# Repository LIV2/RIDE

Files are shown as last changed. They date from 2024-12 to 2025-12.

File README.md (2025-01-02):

# 🏍 RIDE - A500+ Fast Ram + IDE
## IDE + 11.37 Megabyte Fast RAM for the A500/A1000/A2000/CDTV
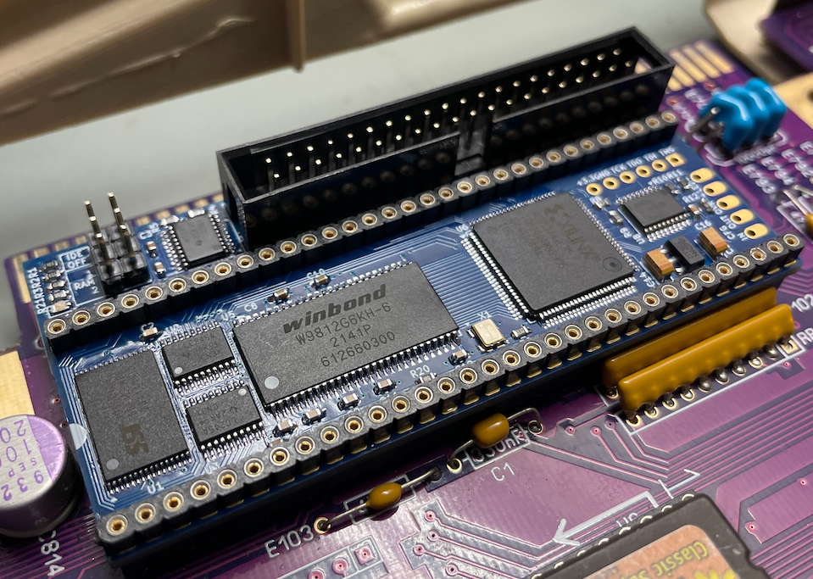
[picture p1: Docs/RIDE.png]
PCB


## Features
- 11.37MB Fast RAM - 1.5MB $C0/Ranger + 8MB Fast + 1.87 Bonus ($A00000)
- Autoboot IDE, Kick 1.3 compatible Open Source driver [lide.device](https://github.com/LIV2/lide.device)
- [Supports up to 2TB drives](https://github.com/LIV2/lide.device/#large-drive-4gb-support)
- Supports ATAPI Devices (CD/DVD-ROM, Zip disk etc - no IDEFix needed)
- Boot from ZIP/LS-120 etc
- [Boot from CD-ROM*](https://github.com/LIV2/lide.device/#boot-from-cdrom)
- SCSI Direct, NSD, TD64 support

## Table of contents
1. [Compatibility](#compatibility)
2. [Jumper settings](#jumper-settings)
3. [Connections](#connections)
4. [Enabling A0 Bonus RAM](#enabling-a0-bonus-ram)
5. [Programming](#programming)
6. [Ordering PCBs](#ordering-pcbs)
    * [PCB Order details](#pcb-order-details)
    * [PCB Assembly](#pcb-assembly)
    * [Bill of Materials](#bill-of-materials)
7. [License](#license)

## Compatibility

Compatible with Kickstart 1.3 and up.

## Jumper settings

**IDE Off**: Close to disable IDE  
**RAM1/RAM2**: Autoconfig RAM configuration
|RAM1|RAM2|Size|
|-|-|----|
|Open|Open|**8 MB**|
|Closed|Open|**4 MB**|
|Open|Closed|**2 MB**|
|Closed|Closed|**Disable**|

## Connections
* **LED**: Activity LED  
* **OVR**: **(Optional)** if connected this will enable the Ranger ($C00000) and Bonus ($A00000) RAM regions.  
Connect OVR to Gary pin 29 or pin 17 of the side expansion port  
* **CFGIN/OUT**: These pins allow this device to co-exist with other Autoconfig devices.
If there are no other Autoconfig devices in your system you can just leave these unconnected.  
If there *are* other Autoconfig devices you will want to use one of these to add the device to the chain.<br /><br />
In the Amiga 2000 you can connect CFGIN to U606 Pin 8 which will add the device to the end of the chain but **NOTE: This takes up the config signal for the leftmost slot (CN601) so do NOT install a Zorro card there**

## Enabling A0 Bonus RAM
The A0 Bonus RAM is not automatically picked up by kickstart and needs to be added using one of the included utilities.  
Note that the `addmem` command from Aminet will **NOT** work - the memory is not enabled until a specific RIDE register is set to enable it

To add the A0 Bonus RAM to the system you will need to use the `addram` command included in the RIDE-Software adf/lha found under [Releases](https://github.com/LIV2/RIDE/releases/latest).

Alternatively you can add the `bootrom` module to a custom kickstart so that this is done automatically at every boot.

## Programming

Program the CPLD using the relevant .jed file below (Right-click, Save as)
|Model|File|
|-----|----|
|A500(+)<br />A1000<br />A2000|[RIDE.jed](https://github.com/LIV2/RIDE/raw/master/Binary/RIDE.jed)|
|CDTV|[RIDE-CDTV.jed](https://github.com/LIV2/RIDE/raw/master/Binary/RIDE-CDTV.jed)|

You can find instructions on how to do that [here](https://linuxjedi.co.uk/2020/12/01/programming-xilinx-jtag-from-a-raspberry-pi/)

The IDE ROM can be programmed by booting from the latest lide-update.adf [here](https://github.com/LIV2/LIDE.device/releases/latest).

## Ordering PCBs

Download the latest Gerbers.zip from the latest release listed on the right-hand side of this page.

Also included in the release are the placement and bom files needed for JLCPCB's assembly service

### PCB Order details
This PCB has been designed to JLCPCB's 4-layer capabilities so I recommend ordering from them

* Layers: 4
* Surface finish: ENIG
* Remove Order Number: Yes

### PCB Assembly
The release files include the relevant BOM and CPL files for JLCPCB's Assembly service  
You can use the following options:  
* PCBA Type: Economic
* Assembly side: Top side
* Confirm Parts Placement: Yes (I recommend checking that all ICs have pin 1 in the correct location etc)

### Bill of materials
**Note**:
* The BOM lists a Mill-Max part for the pin sockets, however you can substitute these for some 9.7mm pin sockets like [these](https://www.aliexpress.com/item/33019740866.html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)  
* The 39SF010 flash can be substituted with 39SF020 or 39SF040 in TSOP-32

[BOM](https://html-preview.github.io/?url=https://github.com/LIV2/RIDE/blob/master/Docs/RIDE_bom.html)  
[HTML Interactive BOM](https://html-preview.github.io/?url=https://github.com/LIV2/RIDE/blob/master/Docs/RIDE-ibom.html)

## Acknowledgements
Thanks to [SukkoPera](https://github.com/SukkoPera) for supporting my early IDE prototype.

## License


This project is licensed under the GPL-2.0 only license

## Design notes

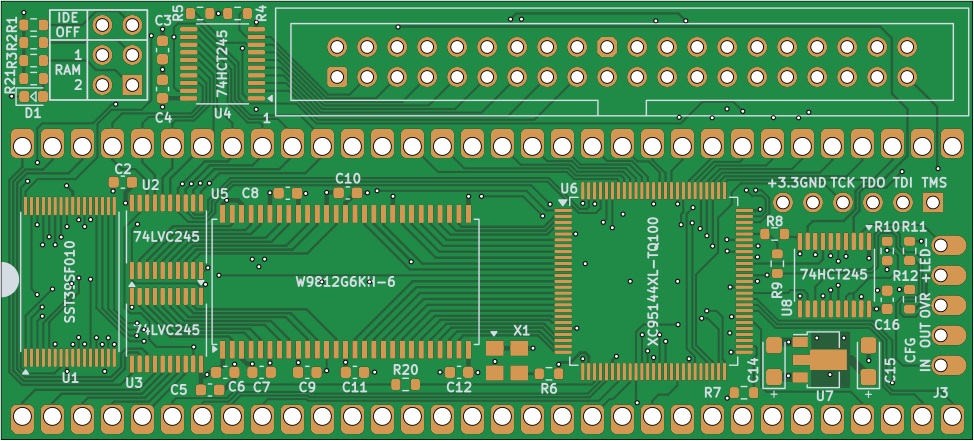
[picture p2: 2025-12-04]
Docs/PCB.png

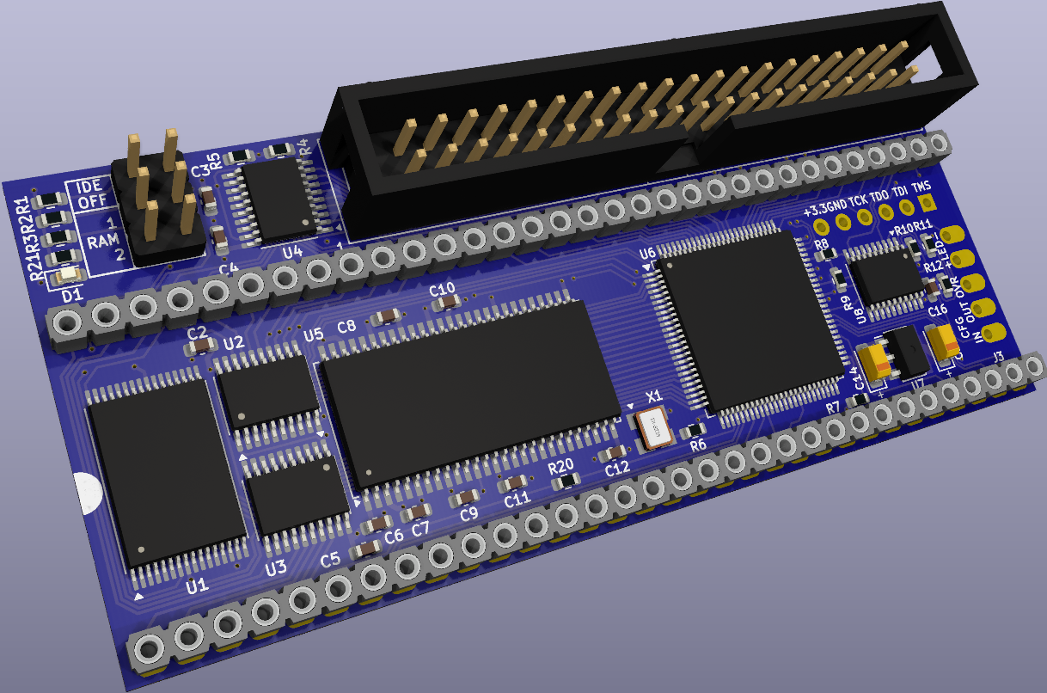
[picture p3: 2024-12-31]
Docs/PCB3D.png

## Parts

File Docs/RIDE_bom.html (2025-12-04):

 | RIDE Bill of materials
Qty | Comment | Designator | Footprint | Mouser Part | Digikey Part | LCSC Part
1 | AMIGA | AMIGA1 | DIP-64_W22.86mm | 575-643166 (https://www.mouser.com/ProductDetail/575-643166) | ED5764-64-ND (https://www.digikey.com/products/en?keywords=ED5764-64-ND) | (https://www.lcsc.com/product-detail/.html)
21 | 0.1u | C1,C2,C3,C4,C5,C6,C7,C8,C9,C10,C11,C12,C13,C16,C17,C18,C19,C20,C22,C23,C24 | C_0603_1608Metric | 80-C603C104K5RAC3121 (https://www.mouser.com/ProductDetail/80-C603C104K5RAC3121) | 399-C0603C104K5RAC3121CT-ND (https://www.digikey.com/products/en?keywords=399-C0603C104K5RAC3121CT-ND) | C14663 (https://www.lcsc.com/product-detail/C14663.html)
2 | 10u | C14,C15 | CP_EIA-3216-18_Kemet-A | 80-T491A106M020 (https://www.mouser.com/ProductDetail/80-T491A106M020) | 399-5152-1-ND (https://www.digikey.com/products/en?keywords=399-5152-1-ND) | C117023 (https://www.lcsc.com/product-detail/C117023.html)
2 | 10u | C21,C25 | C_0805_2012Metric_Pad1.18x1.45mm_HandSolder | 187-CL21A106KQFNNWE (https://www.mouser.com/ProductDetail/187-CL21A106KQFNNWE) | 1276-CL21A106KQFNNWECT-ND (https://www.digikey.com/products/en?keywords=1276-CL21A106KQFNNWECT-ND) | C15850 (https://www.lcsc.com/product-detail/C15850.html)
1 | 47uF | C26 | CP_EIA-3216-18_Kemet-A_Pad1.58x1.35mm_HandSolder | 80-T490A476M10ATE1K (https://www.mouser.com/ProductDetail/80-T490A476M10ATE1K) | 399-T490A476M010ATE1K0CT-ND (https://www.digikey.com/products/en?keywords=399-T490A476M010ATE1K0CT-ND) | C193224 (https://www.lcsc.com/product-detail/C193224.html)
1 | LED | D1 | LED_0603_1608Metric | 696-SML-LX0603GW (https://www.mouser.com/ProductDetail/696-SML-LX0603GW) | 67-1549-1-ND (https://www.digikey.com/products/en?keywords=67-1549-1-ND) | C136120 (https://www.lcsc.com/product-detail/C136120.html)
1 | Polyfuse 500mA Hold | F1 | Fuse_1206_3216Metric_Pad1.42x1.75mm_HandSolder | 576-1206L110-16WR (https://www.mouser.com/ProductDetail/576-1206L110-16WR) | 18-1206L110/16WRCT-ND (https://www.digikey.com/products/en?keywords=18-1206L110/16WRCT-ND) | C21714343 (https://www.lcsc.com/product-detail/C21714343.html)
1 | Conn_02x03_Odd_Even | J4 | PinHeader_2x03_P2.54mm_Vertical | 571-4-146262-1 (https://www.mouser.com/ProductDetail/571-4-146262-1) | 4-146262-1-ND (https://www.digikey.com/products/en?keywords=4-146262-1-ND) | C7501274 (https://www.lcsc.com/product-detail/C7501274.html)
1 | IDE | J1 | IDC-Header_2x20_P2.54mm_Vertical | 737-BHR-40-VUA (https://www.mouser.com/ProductDetail/737-BHR-40-VUA) | 2057-BHR-40-VUA-ND (https://www.digikey.com/products/en?keywords=2057-BHR-40-VUA-ND) | C9138 (https://www.lcsc.com/product-detail/C9138.html)
7 | 33 | R6,R7,R9,R13,R14,R18,R19 | R_0603_1608Metric | 279-CRG0603F33R (https://www.mouser.com/ProductDetail/279-CRG0603F33R) | 1712-CRG0603F33RCT-ND (https://www.digikey.com/products/en?keywords=1712-CRG0603F33RCT-ND) | C23140 (https://www.lcsc.com/product-detail/C23140.html)
3 | 150 | R12,R20,R21 | R_0603_1608Metric | 279-CRGP0603F150R (https://www.mouser.com/ProductDetail/279-CRGP0603F150R) | A130406CT-ND (https://www.digikey.com/products/en?keywords=A130406CT-ND) | C22808 (https://www.lcsc.com/product-detail/C22808.html)
11 | 10k | R1,R2,R3,R4,R5,R8,R10,R11,R15,R16,R17 | R_0603_1608Metric | 279-CRGH0603J10K (https://www.mouser.com/ProductDetail/279-CRGH0603J10K) | A126394CT-ND (https://www.digikey.com/products/en?keywords=A126394CT-ND) | C25804 (https://www.lcsc.com/product-detail/C25804.html)
3 | 74HCT245 | U4,U8,U9 | TSSOP-20_4.4x6.5mm_P0.65mm | 595-SN74HCT245PWR (https://www.mouser.com/ProductDetail/595-SN74HCT245PWR) | 296-8404-1-ND (https://www.digikey.com/products/en?keywords=296-8404-1-ND) | C6779 (https://www.lcsc.com/product-detail/C6779.html)
2 | 74LVC245 | U2,U3 | TSSOP-20_4.4x6.5mm_P0.65mm | 595-SN74LVC245APWR (https://www.mouser.com/ProductDetail/595-SN74LVC245APWR) | 296-1233-1-ND (https://www.digikey.com/products/en?keywords=296-1233-1-ND) | C7848 (https://www.lcsc.com/product-detail/C7848.html)
1 | AZ1117-3.3 | U7 | SOT-89-3 | 621-AZ1117CR-3.3TRG1 (https://www.mouser.com/ProductDetail/621-AZ1117CR-3.3TRG1) | AZ1117CR-3.3TRG1DICT-ND (https://www.digikey.com/products/en?keywords=AZ1117CR-3.3TRG1DICT-ND) | C460428 (https://www.lcsc.com/product-detail/C460428.html)
1 | SST39SF010 | U1 | TSOP-I-32_11.8x8mm_P0.5mm | (https://www.mouser.com/ProductDetail/) | 150-SST39SF010A-70-4C-TU-ND (https://www.digikey.com/products/en?keywords=150-SST39SF010A-70-4C-TU-ND) | (https://www.lcsc.com/product-detail/.html)
1 | W9812G6KH-6 | U5 | TSOP-II-54_22.2x10.16mm_P0.8mm | 454-W9812G6KH-6 (https://www.mouser.com/ProductDetail/454-W9812G6KH-6) | W9812G6KH-6-ND (https://www.digikey.com/products/en?keywords=W9812G6KH-6-ND) | C62379 (https://www.lcsc.com/product-detail/C62379.html)
1 | XC95144XL-TQ100 | U6 | TQFP-100_14x14mm_P0.5mm | 217-5144XL-10TQG100I (https://www.mouser.com/ProductDetail/217-5144XL-10TQG100I) | (https://www.digikey.com/products/en?keywords=) | C45126 (https://www.lcsc.com/product-detail/C45126.html)
1 | 50MHz | X1 | Oscillator_SMD_Abracon_ASE-4Pin_3.2x2.5mm | 520-ECS-2333-500-BNT (https://www.mouser.com/ProductDetail/520-ECS-2333-500-BNT) | XC1930CT-ND (https://www.digikey.com/products/en?keywords=XC1930CT-ND) | C5203552 (https://www.lcsc.com/product-detail/C5203552.html)
Color reference for columns:
KiCad Fields (default)
Generated Fields
User Fields
Empty Fields

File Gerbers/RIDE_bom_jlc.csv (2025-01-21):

Qty | Comment | Designator | Footprint | LCSC Part #
21 | 0.1u | C1,C2,C3,C4,C5,C6,C7,C8,C9,C10,C11,C12,C13,C16,C17,C18,C19,C20,C22,C23,C24 | C_0603_1608Metric | C14663
2 | 10u | C14,C15 | CP_EIA-3216-18_Kemet-A | C117023
2 | 10u | C21,C25 | C_0805_2012Metric_Pad1.18x1.45mm_HandSolder | C15850
1 | 47uF | C26 | CP_EIA-3216-18_Kemet-A_Pad1.58x1.35mm_HandSolder | C193224
1 | LED | D1 | LED_0603_1608Metric | C136120
1 | Polyfuse 500mA Hold | F1 | Fuse_1206_3216Metric_Pad1.42x1.75mm_HandSolder | C21714343
1 | Conn_02x03_Odd_Even | J4 | PinHeader_2x03_P2.54mm_Vertical | C7501274
1 | IDE | J1 | IDC-Header_2x20_P2.54mm_Vertical | C9138
7 | 33 | R6,R7,R9,R13,R14,R18,R19 | R_0603_1608Metric | C23140
3 | 150 | R12,R20,R21 | R_0603_1608Metric | C22808
11 | 10k | R1,R2,R3,R4,R5,R8,R10,R11,R15,R16,R17 | R_0603_1608Metric | C25804
3 | 74HCT245 | U4,U8,U9 | TSSOP-20_4.4x6.5mm_P0.65mm | C6779
2 | 74LVC245 | U2,U3 | TSSOP-20_4.4x6.5mm_P0.65mm | C7848
1 | AZ1117-3.3 | U7 | SOT-89-3 | C460428
1 | SST39SF010 | U1 | TSOP-I-32_11.8x8mm_P0.5mm
1 | W9812G6KH-6 | U5 | TSOP-II-54_22.2x10.16mm_P0.8mm | C62379
1 | XC95144XL-TQ100 | U6 | TQFP-100_14x14mm_P0.5mm | C45126
1 | 50MHz | X1 | Oscillator_SMD_Abracon_ASE-4Pin_3.2x2.5mm | C5203552

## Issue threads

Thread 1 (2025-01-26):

U1 SST39SF010 (and SST39SF020 and SST39SF040) is missing from JLCPCB

emanuelelaface, 2025-01-26:
Hi,

first of all thanks a lot for this great work. I'd love to build one of these memory expansions but I am not so good with tiny SMD to do by myself, so I am trying to order a pre-assembled version from JLCPCB but the U1 memory (the SST39SF010) is out of stock. Every variant like SST39SF020 or SST39SF040 is also not available in TSOP-32, so I wonder if you have a suggestion for a possible change that can work.
Thanks a lot!

LIV2, 2025-01-26:
Hi,

I haven't found any compatible parts that are still produced, and before I released this project the manufacturer discontinued the SST 39SF0x0 devices in TSOP packages

I don't think it's possible to order these parts through JLC parts any more but I do know that Digikey has some 39SF040s in stock for now: https://www.digikey.co.nz/short/n793qm5f

Other than that you would have to order some from eBay / Aliexpress I guess

emanuelelaface, 2025-01-26:
Thank you for your answer. The main problem for me is to solder the TSOP by myself, I will think what to do. Thanks a lot for your quick answer.

danko79, 2025-01-26:
Hi, due to the availability of the TSOP32 package, it is possible to revise the PCB in plcc32 format of the flash, i have same problem.

LIV2, 2025-01-29:
PLCC-32 is much larger, won't fit under the CPU and would need a larger PCB etc so I have no plans to revise it right now sorry.

Closed 2025-01-29.

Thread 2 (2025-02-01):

Anybody selling this?

mankeli, 2025-02-01:
Hi, I wonder if anyone is selling this already?

LIV2, 2025-02-03:
Hi @mankeli,

I'm not aware of anyone who is selling these currently but I'll ask around to see if anyone I know is planning to

LIV2, 2025-02-03:
The CPLD is still in stock at mouser for now:
https://www.mouser.com/ProductDetail/217-5144XL-10TQG100C
And also at LCSC / JLCPCB
https://www.lcsc.com/product-detail/Programmable-Logic-Device-CPLDs-FPGAs_AMD-XILINX-XC95144XL-10TQG100I_C1521163.html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

Digikey have a small amount of SST 39SF040 in stock which can be used for the flash
https://www.digikey.com/en/products/detail/microchip-technology/sst39sf040-70-4c-whe/2297836

Unfortunately there's no pin compatible alternatives for either, replacing the CPLD & Flash will require a lot of redesign work

LIV2, 2025-02-03:
It seems that Microchip have a new part for the flash but there's no stock in any distributors currently
https://www.digikey.co.nz/en/products/detail/microchip-technology/SST39SF010A-70-4C-TU/25903865

Closed 2025-08-10.

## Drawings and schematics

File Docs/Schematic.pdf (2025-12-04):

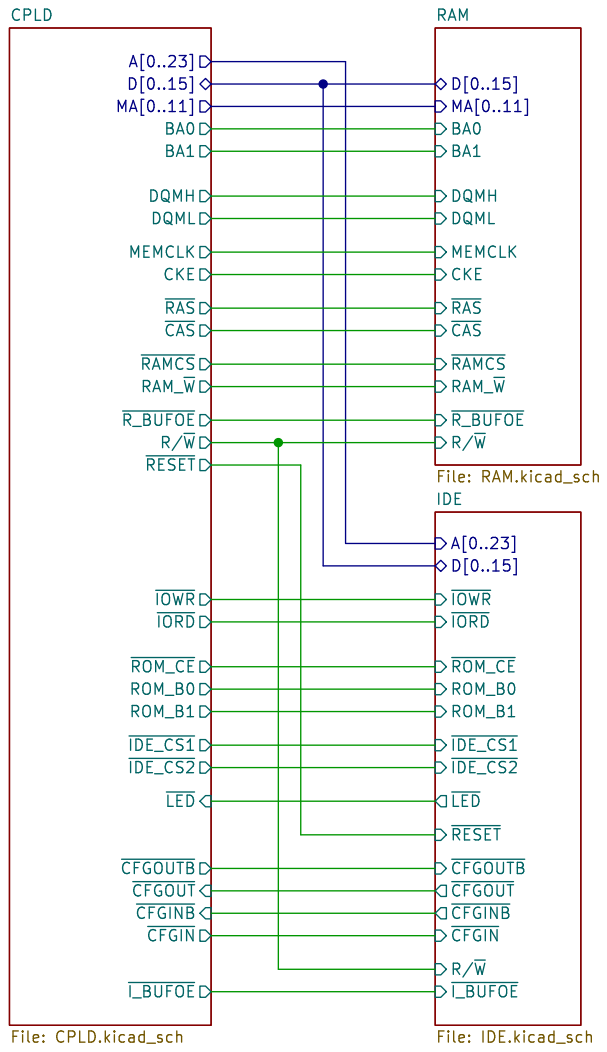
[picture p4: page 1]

Id: 1/4 Title: File: RIDE.kicad_sch Sheet: /

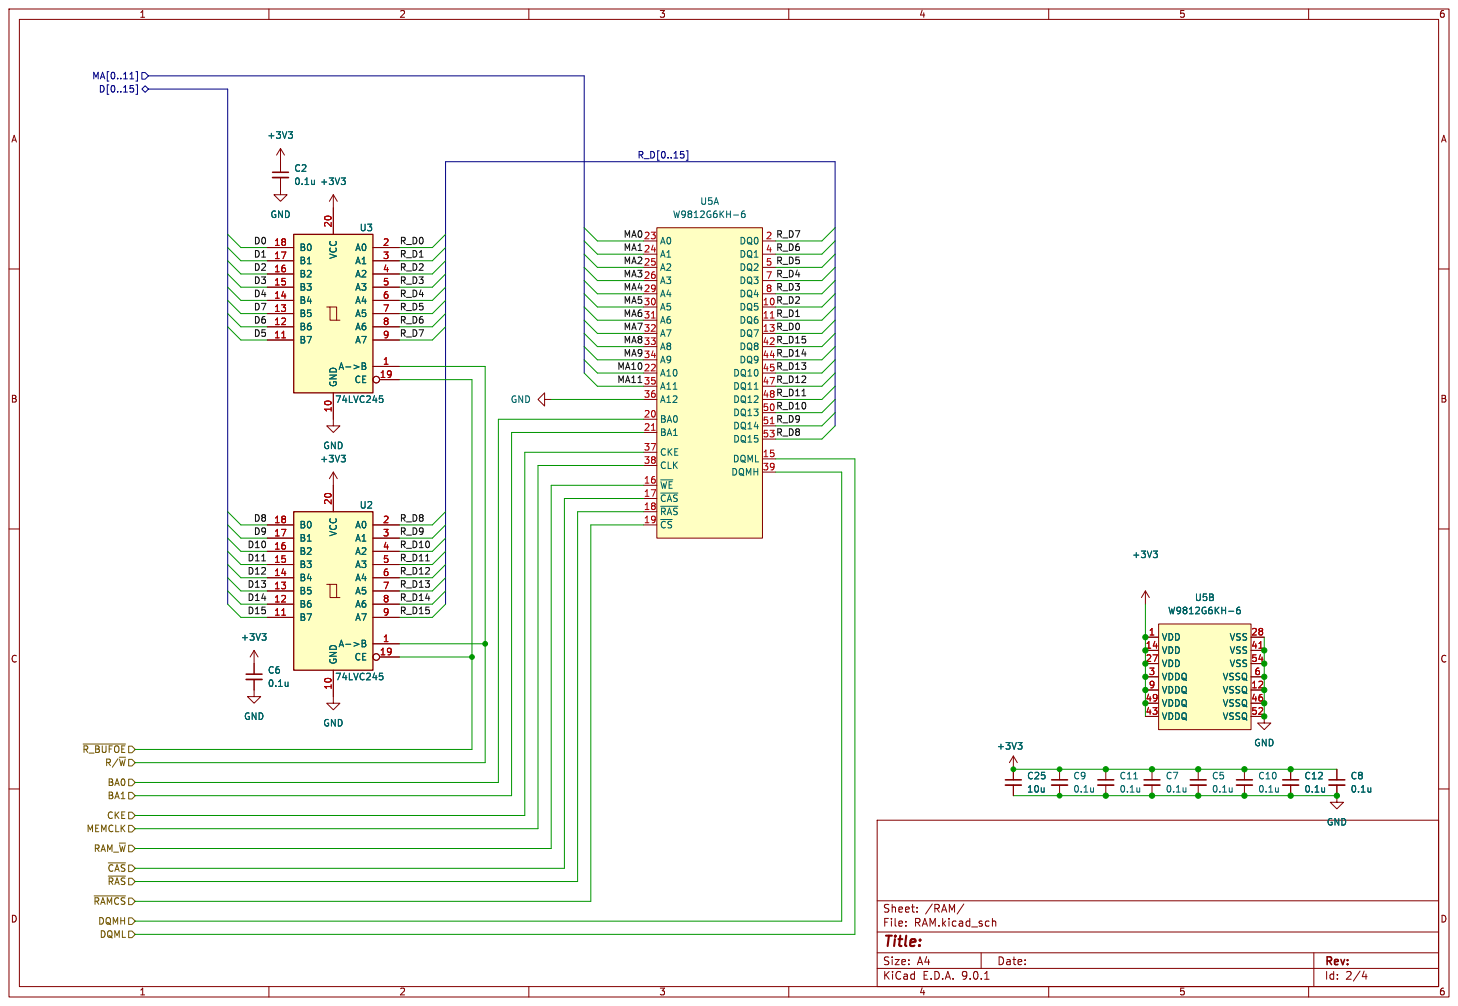
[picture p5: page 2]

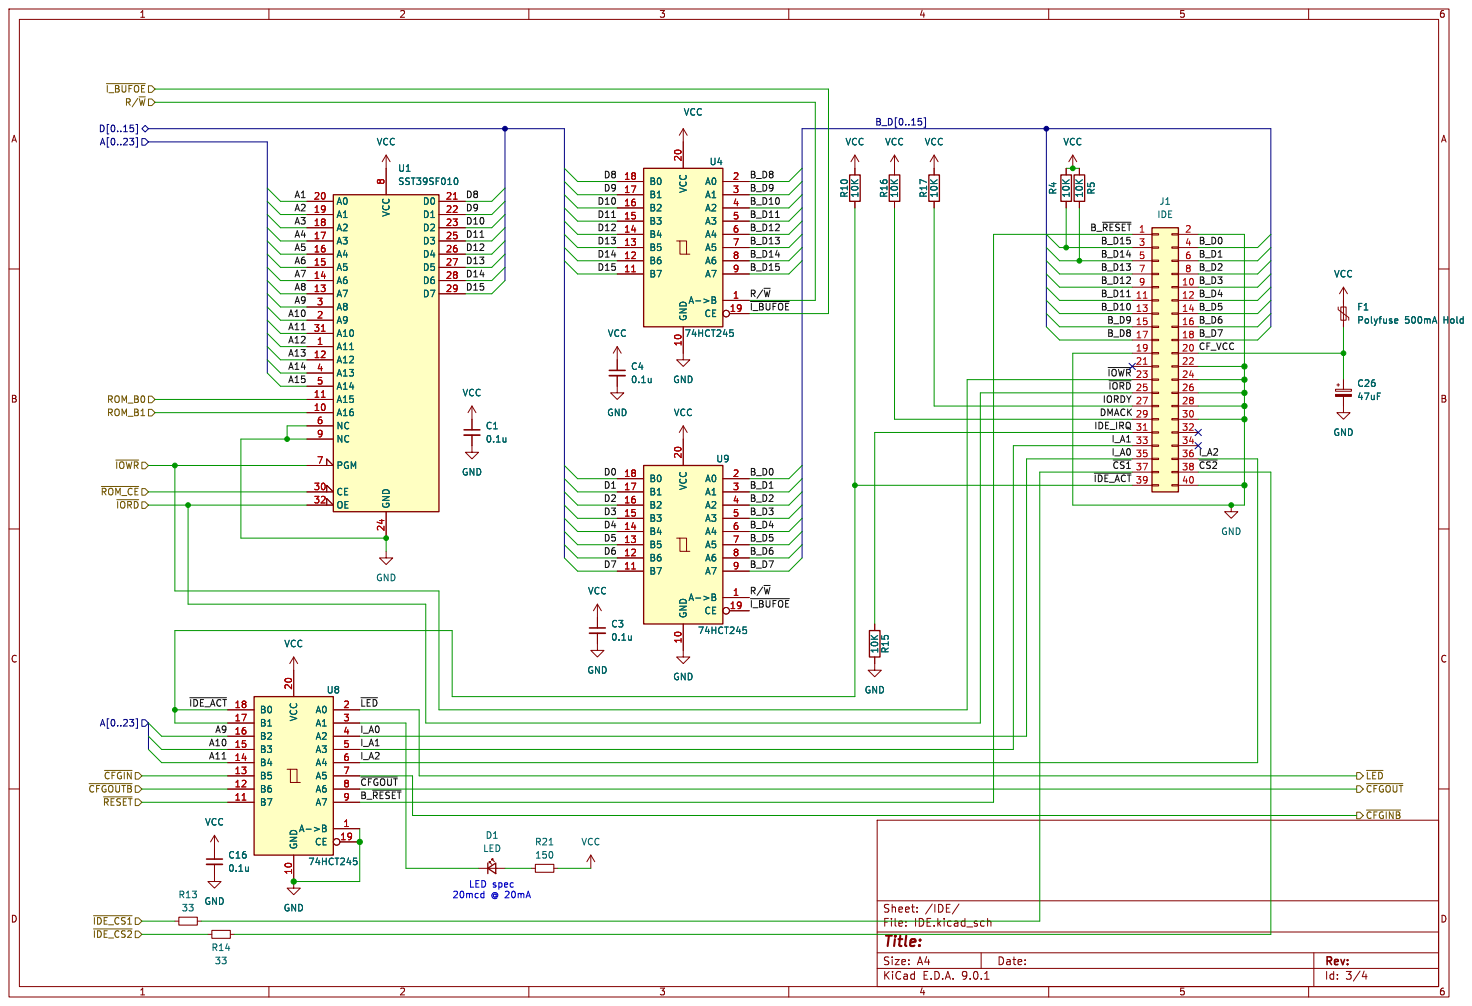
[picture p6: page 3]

Id: 3/4 Title: File: IDE.kicad_sch Sheet: /IDE/

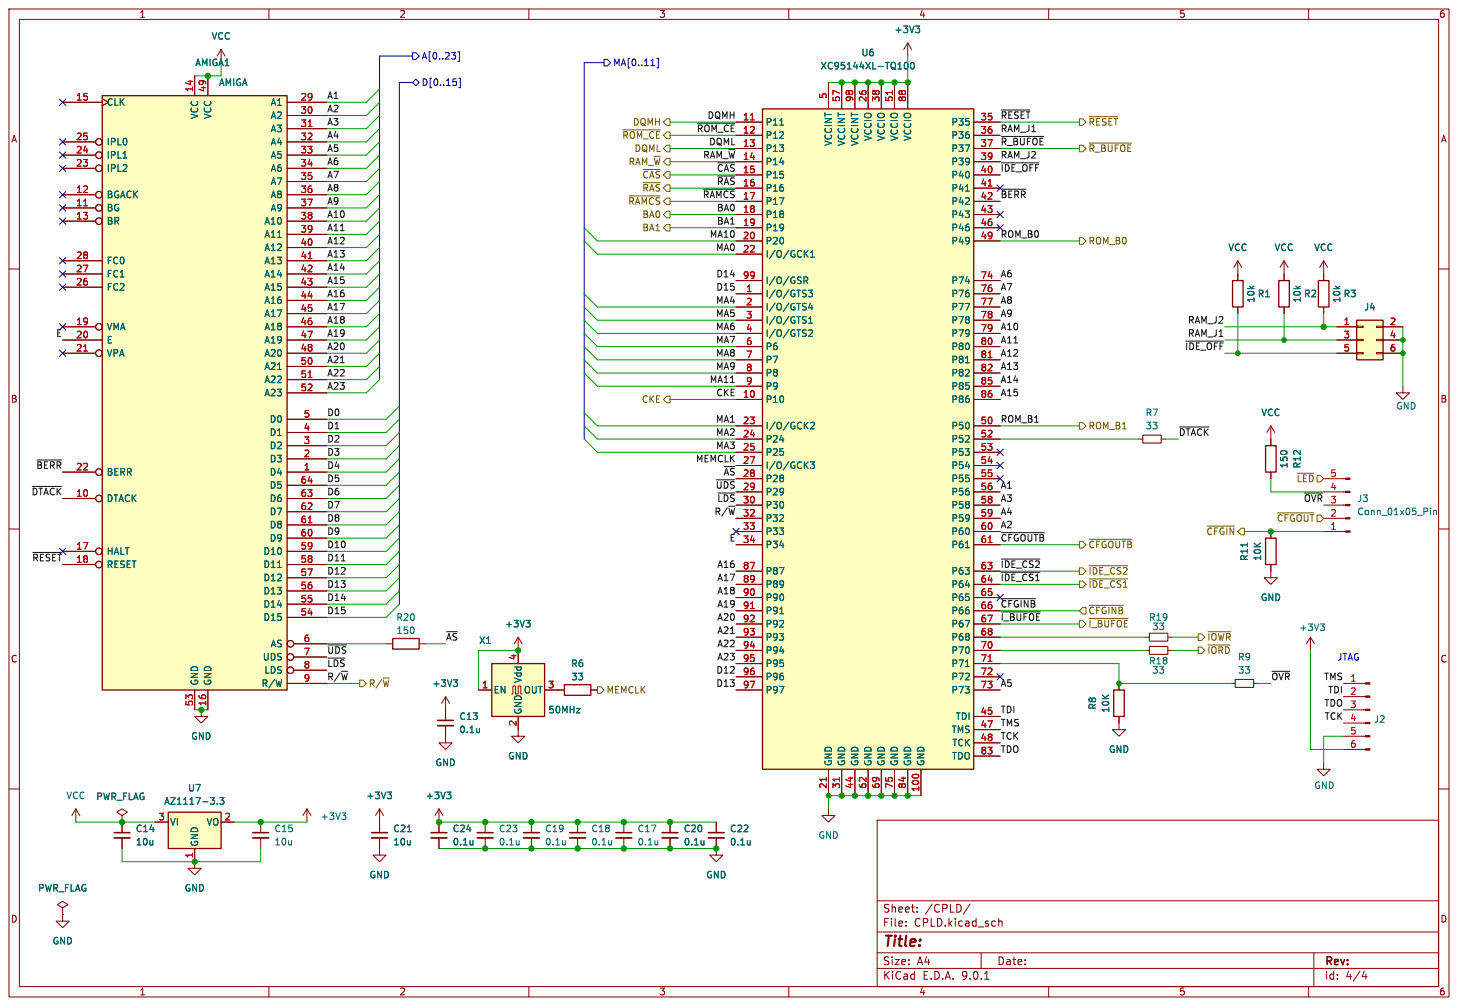
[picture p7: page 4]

5 GND 21 VCCINT 57 GND 31 VCCINT 98 GND 44 VCCIO 26 GND 62 VCCIO 38 GND 69 VCCIO 51 GND 75 VCCIO 88 GND 84 GND 100 P35 35 P36 36 P37 37 P39 39 P40 40 P41 41 P42 42 P43 43 P46 46 P49 49 P74 74 P76 76 P77 77 P78 78 P79 79 P80 80 P81 81 P82 82 P85 85 P86 86 P50 50 P52 52 P53 53 P54 54 P55 55 P56 56 P58 58 P59 59 P60 60 P61 61 P63 63 P64 64 P65 65 P66 66 P67 67 P68 68 P70 70 P71 71 P72 72 P73 73 TDI 45 TMS 47 TCK 48 TDO 83 C22
DQMH

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

Id: 4/4 Title: File: CPLD.kicad_sch Sheet: /CPLD/ C13

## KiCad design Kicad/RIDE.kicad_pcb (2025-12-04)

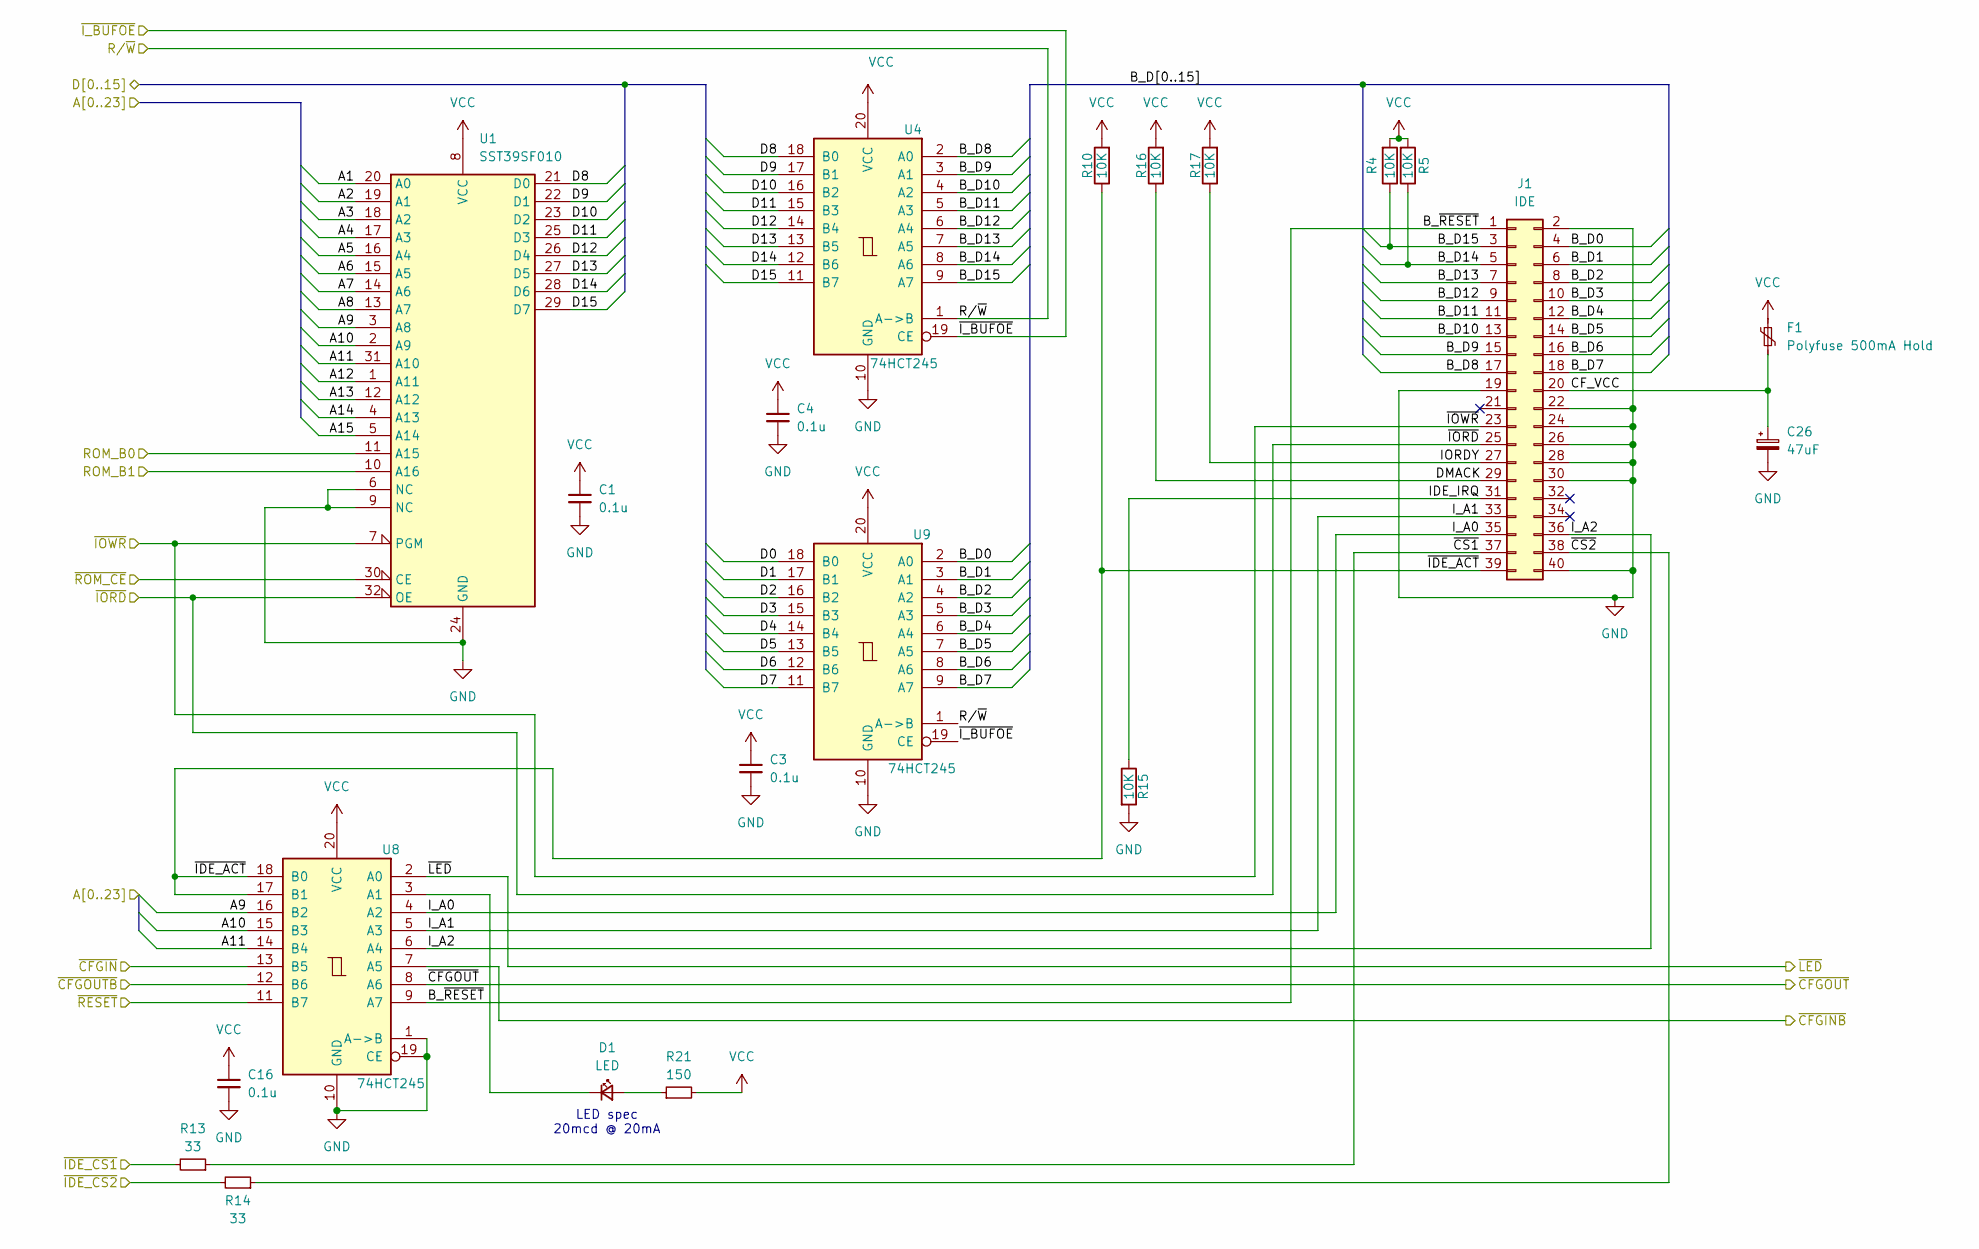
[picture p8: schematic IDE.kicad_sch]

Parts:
C1, C3, C4, C16: 0.1u; C_0603_1608Metric; Mouser # 80-C603C104K5RAC3121; LCSC # C14663
C26: 47uF; CP_EIA-3216-18_Kemet-A_Pad1.58x1.35mm_HandSolder; Mouser # 80-T490A476M10ATE1K; LCSC # C193224
D1: LED; LED_0603_1608Metric; Mouser # 696-SML-LX0603GW; LCSC # C136120
F1: Polyfuse 500mA Hold; Fuse_1206_3216Metric_Pad1.42x1.75mm_HandSolder; Mouser # 576-1206L110-16WR
J1: IDE; IDC-Header_2x20_P2.54mm_Vertical; Mouser # 737-BHR-40-VUA
R4, R5, R10, R15, R16, R17: 10K; R_0603_1608Metric; Mouser # 279-CRGH0603J10K; LCSC # C25804
R13, R14: 33; R_0603_1608Metric; Mouser # 279-CRG0603F33R; LCSC # C23140
R21: 150; R_0603_1608Metric; Mouser # 279-CRGP0603F150R; LCSC # C22808
U1: SST39SF010; TSOP-I-32_11.8x8mm_P0.5mm; Digikey # 150-SST39SF010A-70-4C-TU-ND
U4, U8, U9: 74HCT245; TSSOP-20_4.4x6.5mm_P0.65mm; Mouser # 595-SN74HCT245PWR; LCSC # C6779

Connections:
/CPLD/A1: U1.20 (A0); also elsewhere on the board
/CPLD/A2: U1.19 (A1); also elsewhere on the board
/CPLD/A3: U1.18 (A2); also elsewhere on the board
/CPLD/A4: U1.17 (A3); also elsewhere on the board
/CPLD/A5: U1.16 (A4); also elsewhere on the board
/CPLD/A6: U1.15 (A5); also elsewhere on the board
/CPLD/A7: U1.14 (A6); also elsewhere on the board
/CPLD/A8: U1.13 (A7); also elsewhere on the board
/CPLD/A9: U1.3 (A8), U8.16 (B2); also elsewhere on the board
/CPLD/A10: U1.2 (A9), U8.15 (B3); also elsewhere on the board
/CPLD/A11: U1.31 (A10), U8.14 (B4); also elsewhere on the board
/CPLD/A12: U1.1 (A11); also elsewhere on the board
/CPLD/A13: U1.12 (A12); also elsewhere on the board
/CPLD/A14: U1.4 (A13); also elsewhere on the board
/CPLD/A15: U1.5 (A14); also elsewhere on the board
/CPLD/D0: U9.18 (B0); also elsewhere on the board
/CPLD/D1: U9.17 (B1); also elsewhere on the board
/CPLD/D2: U9.16 (B2); also elsewhere on the board
/CPLD/D3: U9.15 (B3); also elsewhere on the board
/CPLD/D4: U9.14 (B4); also elsewhere on the board
/CPLD/D5: U9.13 (B5); also elsewhere on the board
/CPLD/D6: U9.12 (B6); also elsewhere on the board
/CPLD/D7: U9.11 (B7); also elsewhere on the board
/CPLD/D8: U1.21 (D0), U4.18 (B0); also elsewhere on the board
/CPLD/D9: U1.22 (D1), U4.17 (B1); also elsewhere on the board
/CPLD/D10: U1.23 (D2), U4.16 (B2); also elsewhere on the board
/CPLD/D11: U1.25 (D3), U4.15 (B3); also elsewhere on the board
/CPLD/D12: U1.26 (D4), U4.14 (B4); also elsewhere on the board
/CPLD/D13: U1.27 (D5), U4.13 (B5); also elsewhere on the board
/CPLD/D14: U1.28 (D6), U4.12 (B6); also elsewhere on the board
/CPLD/D15: U1.29 (D7), U4.11 (B7); also elsewhere on the board
/CPLD/ROM_B0: U1.11 (A15); also elsewhere on the board
/CPLD/ROM_B1: U1.10 (A16); also elsewhere on the board
/CPLD/R/~W: U4.1 (A->B), U9.1 (A->B); also elsewhere on the board
/CPLD/~CFGINB: U8.7 (A5); also elsewhere on the board
/CPLD/~CFGIN: U8.13 (B5); also elsewhere on the board
/CPLD/~CFGOUTB: U8.12 (B6); also elsewhere on the board
/CPLD/~IDE_CS1: R13.2; also elsewhere on the board
/CPLD/~IDE_CS2: R14.2; also elsewhere on the board
/CPLD/~I_BUFOE: U4.19 (CE), U9.19 (CE); also elsewhere on the board
/CPLD/~RESET: U8.11 (B7); also elsewhere on the board
/CPLD/~ROM_CE: U1.30 (CE); also elsewhere on the board
/IDE/B_D0: J1.4, U9.2 (A0)
/IDE/B_D1: J1.6, U9.3 (A1)
/IDE/B_D2: J1.8, U9.4 (A2)
/IDE/B_D3: J1.10, U9.5 (A3)
/IDE/B_D4: J1.12, U9.6 (A4)
/IDE/B_D5: J1.14, U9.7 (A5)
/IDE/B_D6: J1.16, U9.8 (A6)
/IDE/B_D7: J1.18, U9.9 (A7)
/IDE/B_D8: J1.17, U4.2 (A0)
/IDE/B_D9: J1.15, U4.3 (A1)
/IDE/B_D10: J1.13, U4.4 (A2)
/IDE/B_D11: J1.11, U4.5 (A3)
/IDE/B_D12: J1.9, U4.6 (A4)
/IDE/B_D13: J1.7, U4.7 (A5)
/IDE/B_D14: J1.5, R5.1, U4.8 (A6)
/IDE/B_D15: J1.3, R4.1, U4.9 (A7)
/IDE/B_~RESET: J1.1, U8.9 (A7)
/IDE/CF_VCC: C26.1, F1.2, J1.20
/IDE/DMACK: J1.29, R16.1
/IDE/IDE_IRQ: J1.31, R15.1
/IDE/IORDY: J1.27, R17.1
/IDE/I_A0: J1.35, U8.4 (A2)
/IDE/I_A1: J1.33, U8.5 (A3)
/IDE/I_A2: J1.36, U8.6 (A4)
/IDE/~CFGOUT: U8.8 (A6); also elsewhere on the board
/IDE/~CS1: J1.37, R13.1
/IDE/~CS2: J1.38, R14.1
/IDE/~IDE_ACT: J1.39, R10.1, U8.17 (B1), U8.18 (B0)
/IDE/~IORD: J1.25, U1.32 (OE); also elsewhere on the board
/IDE/~IOWR: J1.23, U1.7 (PGM); also elsewhere on the board
/IDE/~LED: U8.2 (A0); also elsewhere on the board
GND: C1.2, C3.2, C4.2, C16.2, C26.2, J1.2, J1.19, J1.22, J1.24, J1.26, J1.28, J1.30, J1.40, R15.2, U1.6 (NC), U1.9 (NC), U1.24 (GND), U4.10 (GND), U8.1 (A->B), U8.10 (GND), U8.19 (CE), U9.10 (GND); also elsewhere on the board
unnamed: D1.2 (A), R21.1
unnamed: D1.1 (K), U8.3 (A1)
VCC: C1.1, C3.1, C4.1, C16.1, F1.1, R4.2, R5.2, R10.2, R16.2, R17.2, R21.2, U1.8 (VCC), U4.20 (VCC), U8.20 (VCC), U9.20 (VCC); also elsewhere on the board

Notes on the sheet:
LED spec 20mcd @ 20mA

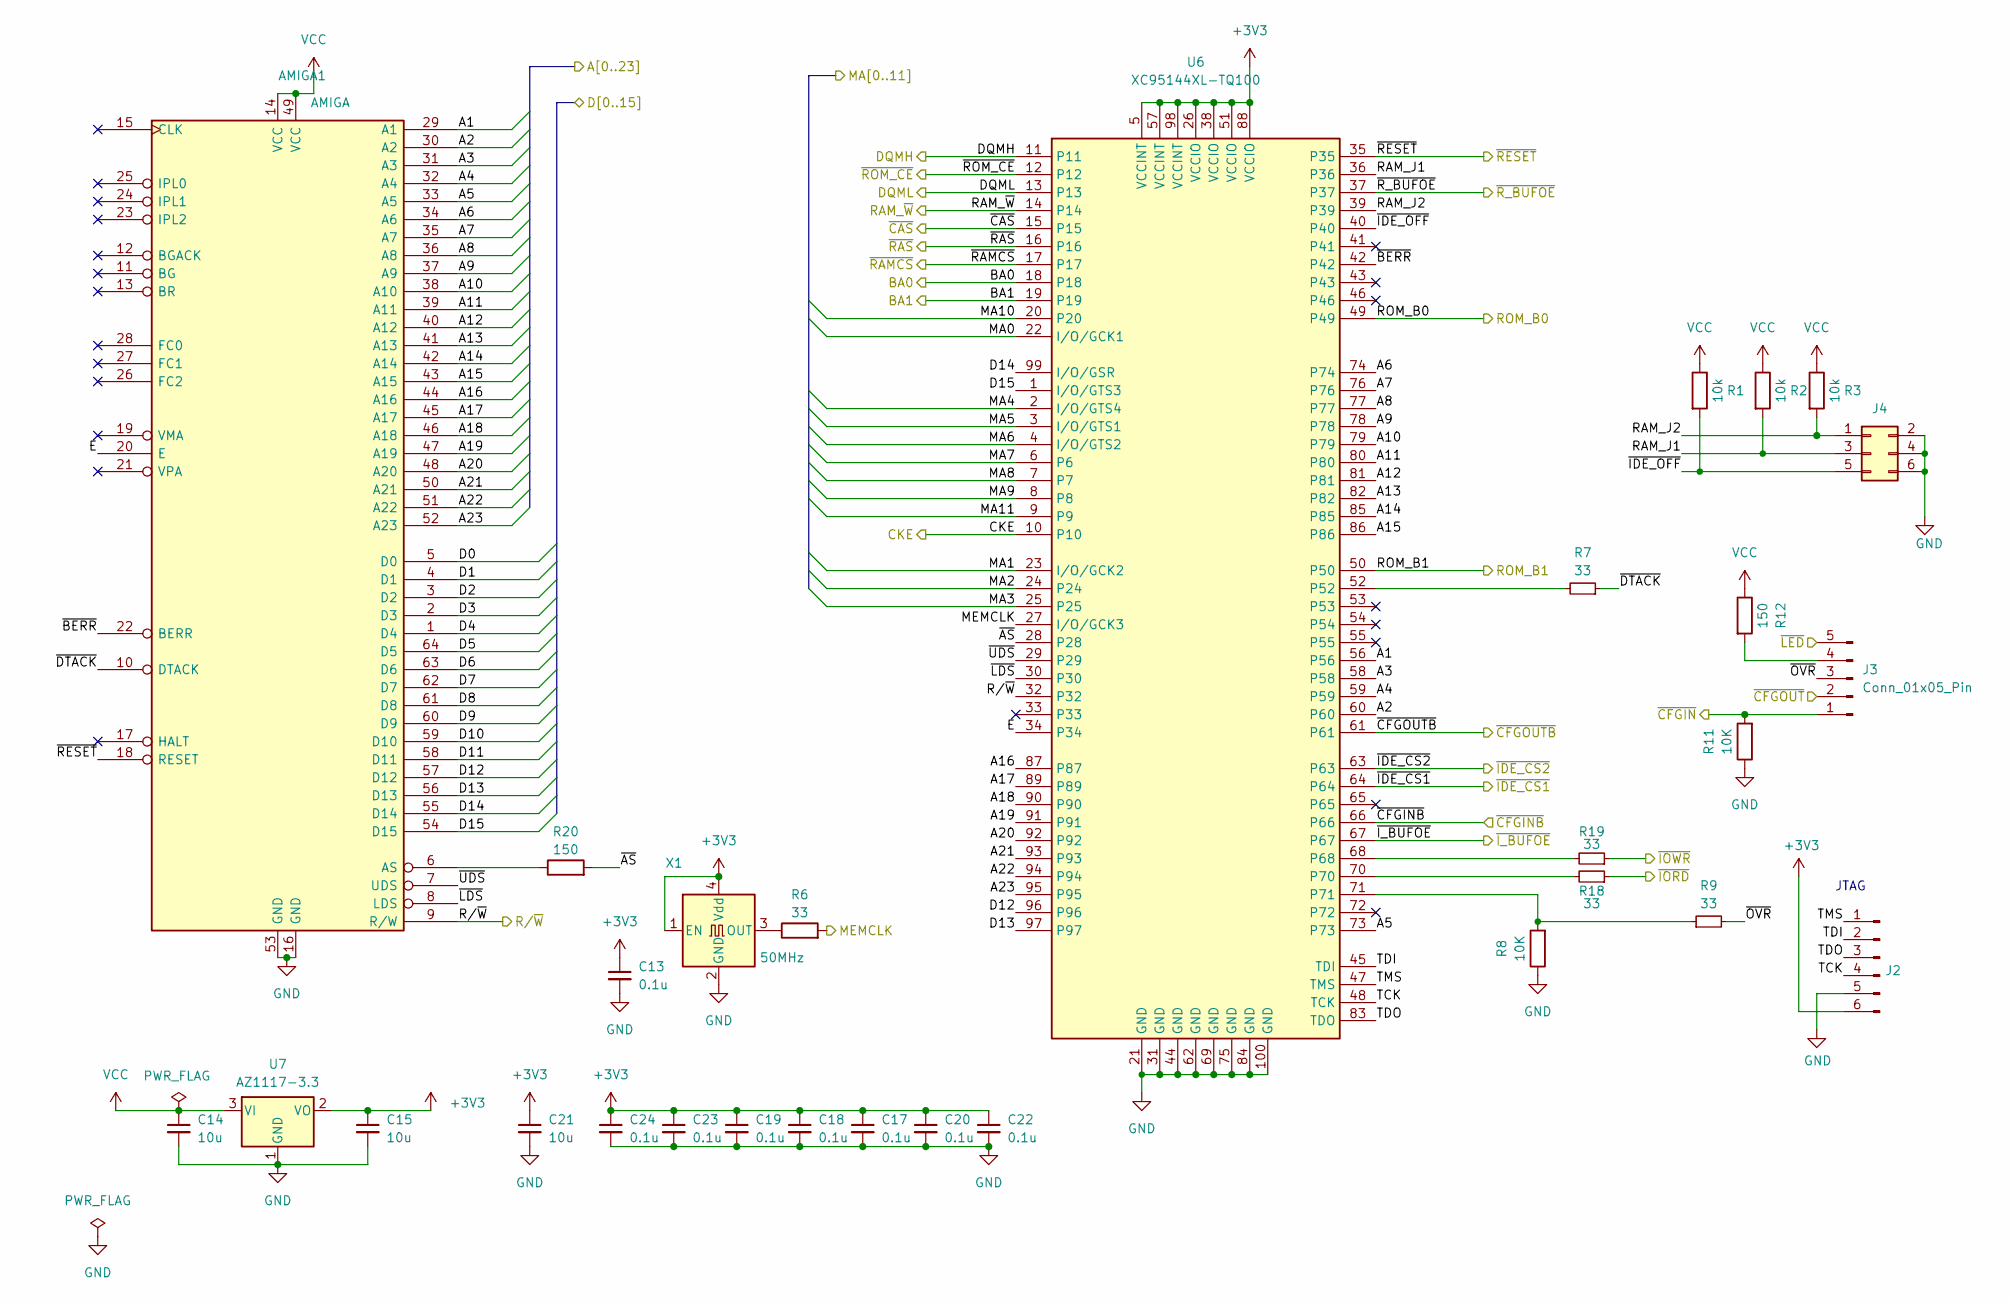
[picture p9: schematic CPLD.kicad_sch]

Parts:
AMIGA1: AMIGA; DIP-64_W22.86mm; Mouser # 575-643166
C13, C17, C18, C19, C20, C22, C23, C24: 0.1u; C_0603_1608Metric; Mouser # 80-C603C104K5RAC3121; LCSC # C14663
C14, C15: 10u; CP_EIA-3216-18_Kemet-A; Mouser # 80-T491A106M020; LCSC # C117023
C21: 10u; C_0805_2012Metric_Pad1.18x1.45mm_HandSolder; Mouser # 187-CL21A106KQFNNWE; LCSC # C15850
J2: Conn_01x06_Male; PinHeader_1x06_P2.54mm_Vertical
J3: Conn_01x05_Pin; PinHeader_1x05_P2.54mm_Vertical
J4: Conn_02x03_Odd_Even; PinHeader_2x03_P2.54mm_Vertical; Mouser # 571-4-146262-1
R1, R2, R3: 10k; R_0603_1608Metric; Mouser # 279-CRGH0603J10K; LCSC # C25804
R6, R7, R9, R18, R19: 33; R_0603_1608Metric; Mouser # 279-CRG0603F33R; LCSC # C23140
R8, R11: 10K; R_0603_1608Metric; Mouser # 279-CRGH0603J10K; LCSC # C25804
R12, R20: 150; R_0603_1608Metric; Mouser # 279-CRGP0603F150R; LCSC # C22808
U6: XC95144XL-TQ100; TQFP-100_14x14mm_P0.5mm; Mouser # 217-5144XL-10TQG100I; LCSC # C45126
U7: AZ1117-3.3; SOT-89-3; Mouser # 621-AZ1117CR-3.3TRG1; LCSC # C460428
X1: 50MHz; Oscillator_SMD_Abracon_ASE-4Pin_3.2x2.5mm; Mouser # 520-ECS-2333-500-BNT; LCSC # C5203552

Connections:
+3V3: C13.1, C15.1, C17.1, C18.1, C19.1, C20.1, C21.1, C22.1, C23.1, C24.1, J2.6, U6.5 (VCCINT), U6.26 (VCCIO), U6.38 (VCCIO), U6.51 (VCCIO), U6.57 (VCCINT), U6.88 (VCCIO), U6.98 (VCCINT), U7.2 (VO), X1.1 (EN), X1.4 (Vdd); also elsewhere on the board
/CPLD/A1: AMIGA1.29 (A1), U6.56; also elsewhere on the board
/CPLD/A2: AMIGA1.30 (A2), U6.60; also elsewhere on the board
/CPLD/A3: AMIGA1.31 (A3), U6.58; also elsewhere on the board
/CPLD/A4: AMIGA1.32 (A4), U6.59; also elsewhere on the board
/CPLD/A5: AMIGA1.33 (A5), U6.73; also elsewhere on the board
/CPLD/A6: AMIGA1.34 (A6), U6.74; also elsewhere on the board
/CPLD/A7: AMIGA1.35 (A7), U6.76; also elsewhere on the board
/CPLD/A8: AMIGA1.36 (A8), U6.77; also elsewhere on the board
/CPLD/A9: AMIGA1.37 (A9), U6.78; also elsewhere on the board
/CPLD/A10: AMIGA1.38 (A10), U6.79; also elsewhere on the board
/CPLD/A11: AMIGA1.39 (A11), U6.80; also elsewhere on the board
/CPLD/A12: AMIGA1.40 (A12), U6.81; also elsewhere on the board
/CPLD/A13: AMIGA1.41 (A13), U6.82; also elsewhere on the board
/CPLD/A14: AMIGA1.42 (A14), U6.85; also elsewhere on the board
/CPLD/A15: AMIGA1.43 (A15), U6.86; also elsewhere on the board
/CPLD/A16: AMIGA1.44 (A16), U6.87
/CPLD/A17: AMIGA1.45 (A17), U6.89
/CPLD/A18: AMIGA1.46 (A18), U6.90
/CPLD/A19: AMIGA1.47 (A19), U6.91
/CPLD/A20: AMIGA1.48 (A20), U6.92
/CPLD/A21: AMIGA1.50 (A21), U6.93
/CPLD/A22: AMIGA1.51 (A22), U6.94
/CPLD/A23: AMIGA1.52 (A23), U6.95
/CPLD/BA0: U6.18; also elsewhere on the board
/CPLD/BA1: U6.19; also elsewhere on the board
/CPLD/CKE: U6.10; also elsewhere on the board
/CPLD/D0: AMIGA1.5 (D0); also elsewhere on the board
/CPLD/D1: AMIGA1.4 (D1); also elsewhere on the board
/CPLD/D2: AMIGA1.3 (D2); also elsewhere on the board
/CPLD/D3: AMIGA1.2 (D3); also elsewhere on the board
/CPLD/D4: AMIGA1.1 (D4); also elsewhere on the board
/CPLD/D5: AMIGA1.64 (D5); also elsewhere on the board
/CPLD/D6: AMIGA1.63 (D6); also elsewhere on the board
/CPLD/D7: AMIGA1.62 (D7); also elsewhere on the board
/CPLD/D8: AMIGA1.61 (D8); also elsewhere on the board
/CPLD/D9: AMIGA1.60 (D9); also elsewhere on the board
/CPLD/D10: AMIGA1.59 (D10); also elsewhere on the board
/CPLD/D11: AMIGA1.58 (D11); also elsewhere on the board
/CPLD/D12: AMIGA1.57 (D12), U6.96; also elsewhere on the board
/CPLD/D13: AMIGA1.56 (D13), U6.97; also elsewhere on the board
/CPLD/D14: AMIGA1.55 (D14), U6.99 (I/O/GSR); also elsewhere on the board
/CPLD/D15: AMIGA1.54 (D15), U6.1 (I/O/GTS3); also elsewhere on the board
/CPLD/DQMH: U6.11; also elsewhere on the board
/CPLD/DQML: U6.13; also elsewhere on the board
/CPLD/E: AMIGA1.20 (E), U6.34
/CPLD/MA0: U6.22 (I/O/GCK1); also elsewhere on the board
/CPLD/MA1: U6.23 (I/O/GCK2); also elsewhere on the board
/CPLD/MA2: U6.24; also elsewhere on the board
/CPLD/MA3: U6.25; also elsewhere on the board
/CPLD/MA4: U6.2 (I/O/GTS4); also elsewhere on the board
/CPLD/MA5: U6.3 (I/O/GTS1); also elsewhere on the board
/CPLD/MA6: U6.4 (I/O/GTS2); also elsewhere on the board
/CPLD/MA7: U6.6; also elsewhere on the board
/CPLD/MA8: U6.7; also elsewhere on the board
/CPLD/MA9: U6.8; also elsewhere on the board
/CPLD/MA10: U6.20; also elsewhere on the board
/CPLD/MA11: U6.9; also elsewhere on the board
/CPLD/MEMCLK: R6.2, U6.27 (I/O/GCK3); also elsewhere on the board
/CPLD/RAM_J1: J4.3, R2.2, U6.36
/CPLD/RAM_J2: J4.1, R3.2, U6.39
/CPLD/RAM_~W: U6.14; also elsewhere on the board
/CPLD/ROM_B0: U6.49; also elsewhere on the board
/CPLD/ROM_B1: U6.50; also elsewhere on the board
/CPLD/R/~W: AMIGA1.9 (R/W), U6.32; also elsewhere on the board
/CPLD/TCK: J2.4, U6.48 (TCK)
/CPLD/TDI: J2.2, U6.45 (TDI)
/CPLD/TDO: J2.3, U6.83 (TDO)
/CPLD/TMS: J2.1, U6.47 (TMS)
/CPLD/~AS: R20.2, U6.28
/CPLD/~BERR: AMIGA1.22 (BERR), U6.42
/CPLD/~CAS: U6.15; also elsewhere on the board
/CPLD/~CFGINB: U6.66; also elsewhere on the board
/CPLD/~CFGIN: J3.1, R11.2; also elsewhere on the board
/CPLD/~CFGOUTB: U6.61; also elsewhere on the board
/CPLD/~DTACK: AMIGA1.10 (DTACK), R7.1
/CPLD/~IDE_CS1: U6.64; also elsewhere on the board
/CPLD/~IDE_CS2: U6.63; also elsewhere on the board
/CPLD/~IDE_OFF: J4.5, R1.2, U6.40
/CPLD/~I_BUFOE: U6.67; also elsewhere on the board
/CPLD/~LDS: AMIGA1.8 (LDS), U6.30
/CPLD/~OVR: J3.3, R9.2
/CPLD/~RAMCS: U6.17; also elsewhere on the board
/CPLD/~RAS: U6.16; also elsewhere on the board
/CPLD/~RESET: AMIGA1.18 (RESET), U6.35; also elsewhere on the board
/CPLD/~ROM_CE: U6.12; also elsewhere on the board
/CPLD/~R_BUFOE: U6.37; also elsewhere on the board
/CPLD/~UDS: AMIGA1.7 (UDS), U6.29
/IDE/~CFGOUT: J3.2; also elsewhere on the board
/IDE/~IORD: R18.1; also elsewhere on the board
/IDE/~IOWR: R19.1; also elsewhere on the board
/IDE/~LED: J3.5; also elsewhere on the board
GND: AMIGA1.16 (GND), AMIGA1.53 (GND), C13.2, C14.2, C15.2, C17.2, C18.2, C19.2, C20.2, C21.2, C22.2, C23.2, C24.2, J2.5, J4.2, J4.4, J4.6, R8.1, R11.1, U6.21 (GND), U6.31 (GND), U6.44 (GND), U6.62 (GND), U6.69 (GND), U6.75 (GND), U6.84 (GND), U6.100 (GND), U7.1 (GND), X1.2 (GND); also elsewhere on the board
unnamed: AMIGA1.6 (AS), R20.1
unnamed: J3.4, R12.2
unnamed: R7.2, U6.52
unnamed: R19.2, U6.68
unnamed: R18.2, U6.70
unnamed: R8.2, R9.1, U6.71
unnamed: R6.1, X1.3 (OUT)
VCC: AMIGA1.14 (VCC), AMIGA1.49 (VCC), C14.1, R1.1, R2.1, R3.1, R12.1, U7.3 (VI); also elsewhere on the board

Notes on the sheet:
JTAG

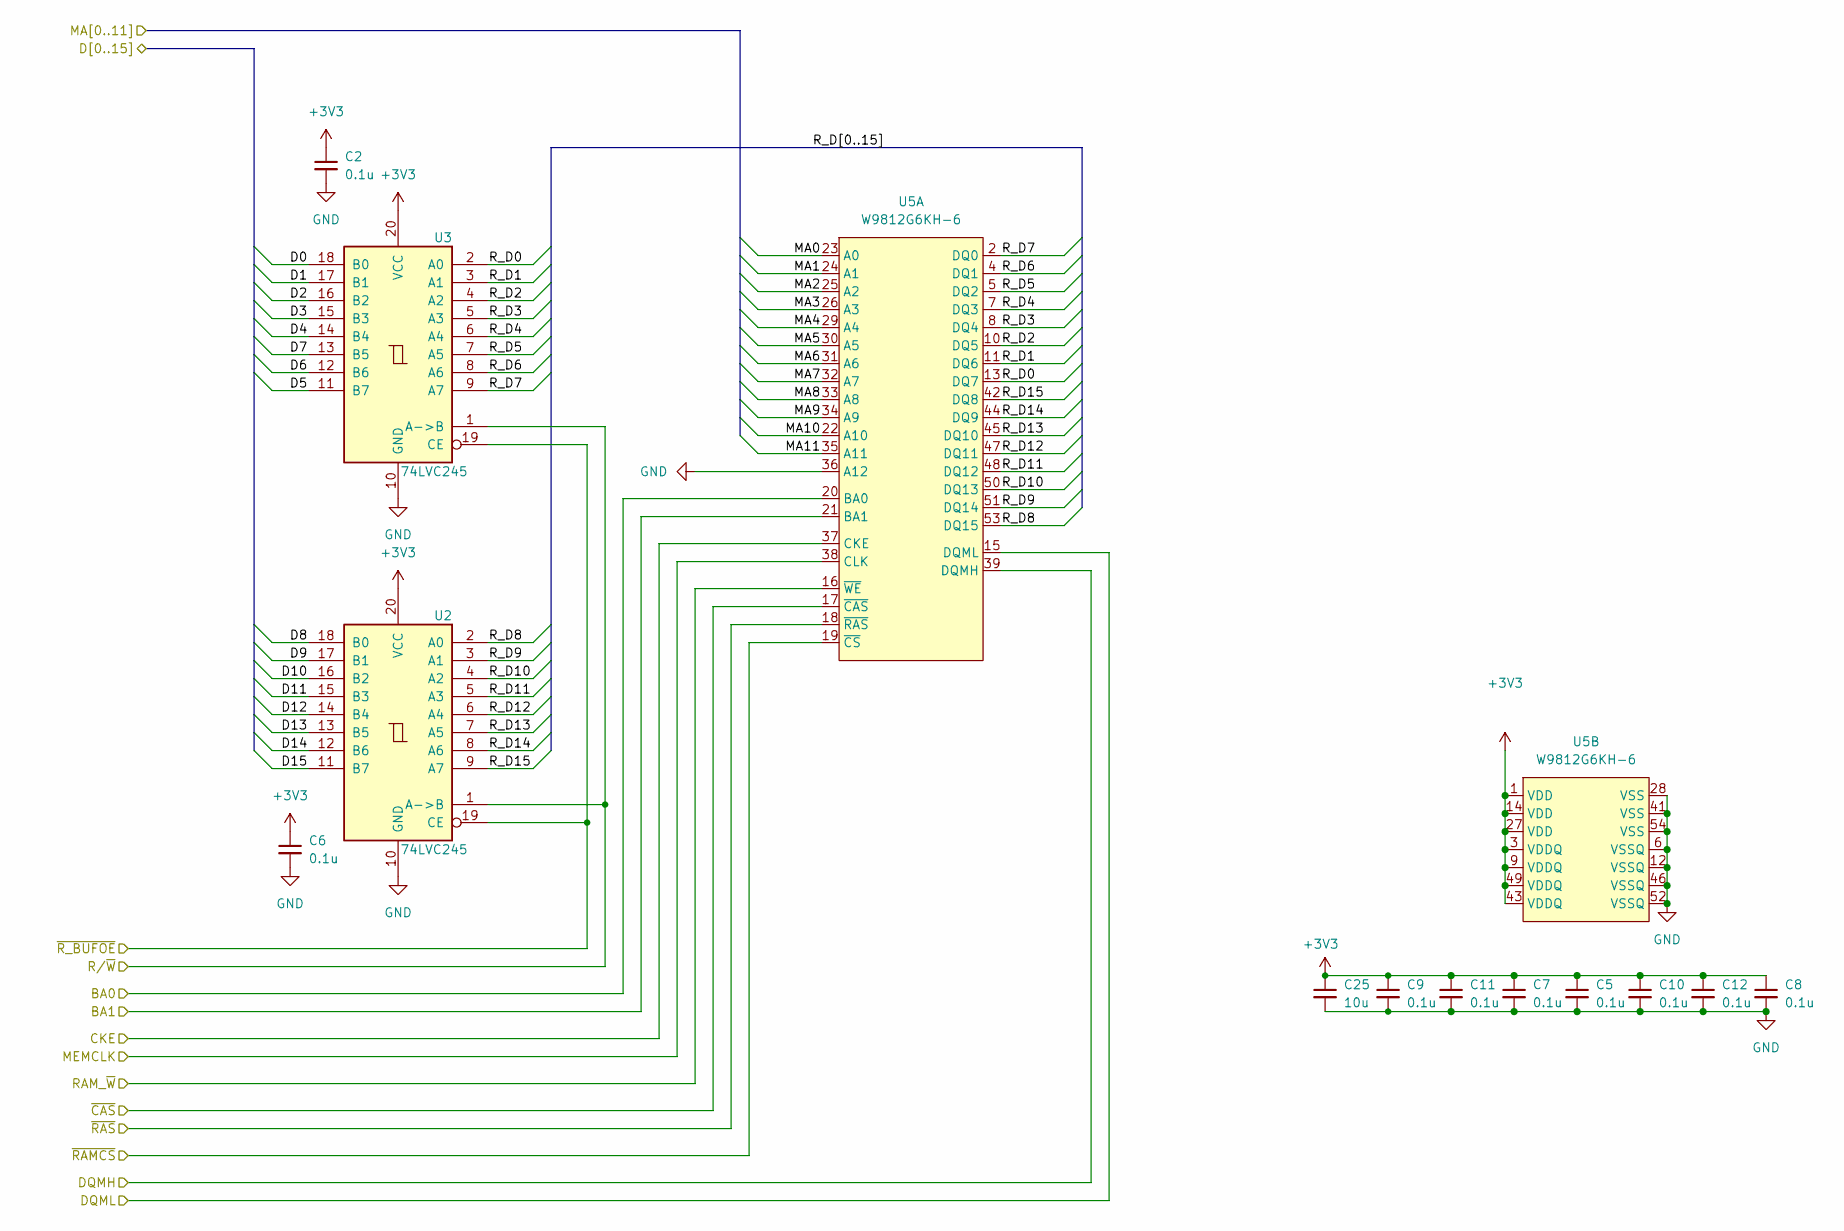
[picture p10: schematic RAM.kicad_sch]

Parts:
C2, C5, C6, C7, C8, C9, C10, C11, C12: 0.1u; C_0603_1608Metric; Mouser # 80-C603C104K5RAC3121; LCSC # C14663
C25: 10u; C_0805_2012Metric_Pad1.18x1.45mm_HandSolder; Mouser # 187-CL21A106KQFNNWE; LCSC # C15850
U2, U3: 74LVC245; TSSOP-20_4.4x6.5mm_P0.65mm; Mouser # 595-SN74LVC245APWR; LCSC # C7848
U5: W9812G6KH-6; TSOP-II-54_22.2x10.16mm_P0.8mm; Mouser # 454-W9812G6KH-6; LCSC # C62379

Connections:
+3V3: C2.1, C5.1, C6.1, C7.1, C8.1, C9.1, C10.1, C11.1, C12.1, C25.1, U2.20 (VCC), U3.20 (VCC), U5.1 (VDD), U5.3 (VDDQ), U5.9 (VDDQ), U5.14 (VDD), U5.27 (VDD), U5.43 (VDDQ), U5.49 (VDDQ); also elsewhere on the board
/CPLD/BA0: U5.20 (BA0); also elsewhere on the board
/CPLD/BA1: U5.21 (BA1); also elsewhere on the board
/CPLD/CKE: U5.37 (CKE); also elsewhere on the board
/CPLD/D0: U3.18 (B0); also elsewhere on the board
/CPLD/D1: U3.17 (B1); also elsewhere on the board
/CPLD/D2: U3.16 (B2); also elsewhere on the board
/CPLD/D3: U3.15 (B3); also elsewhere on the board
/CPLD/D4: U3.14 (B4); also elsewhere on the board
/CPLD/D5: U3.11 (B7); also elsewhere on the board
/CPLD/D6: U3.12 (B6); also elsewhere on the board
/CPLD/D7: U3.13 (B5); also elsewhere on the board
/CPLD/D8: U2.18 (B0); also elsewhere on the board
/CPLD/D9: U2.17 (B1); also elsewhere on the board
/CPLD/D10: U2.16 (B2); also elsewhere on the board
/CPLD/D11: U2.15 (B3); also elsewhere on the board
/CPLD/D12: U2.14 (B4); also elsewhere on the board
/CPLD/D13: U2.13 (B5); also elsewhere on the board
/CPLD/D14: U2.12 (B6); also elsewhere on the board
/CPLD/D15: U2.11 (B7); also elsewhere on the board
/CPLD/DQMH: U5.39 (DQMH); also elsewhere on the board
/CPLD/DQML: U5.15 (DQML); also elsewhere on the board
/CPLD/MA0: U5.23 (A0); also elsewhere on the board
/CPLD/MA1: U5.24 (A1); also elsewhere on the board
/CPLD/MA2: U5.25 (A2); also elsewhere on the board
/CPLD/MA3: U5.26 (A3); also elsewhere on the board
/CPLD/MA4: U5.29 (A4); also elsewhere on the board
/CPLD/MA5: U5.30 (A5); also elsewhere on the board
/CPLD/MA6: U5.31 (A6); also elsewhere on the board
/CPLD/MA7: U5.32 (A7); also elsewhere on the board
/CPLD/MA8: U5.33 (A8); also elsewhere on the board
/CPLD/MA9: U5.34 (A9); also elsewhere on the board
/CPLD/MA10: U5.22 (A10); also elsewhere on the board
/CPLD/MA11: U5.35 (A11); also elsewhere on the board
/CPLD/MEMCLK: U5.38 (CLK); also elsewhere on the board
/CPLD/RAM_~W: U5.16 (~WE); also elsewhere on the board
/CPLD/R/~W: U2.1 (A->B), U3.1 (A->B); also elsewhere on the board
/CPLD/~CAS: U5.17 (~CAS); also elsewhere on the board
/CPLD/~RAMCS: U5.19 (~CS); also elsewhere on the board
/CPLD/~RAS: U5.18 (~RAS); also elsewhere on the board
/CPLD/~R_BUFOE: U2.19 (CE), U3.19 (CE); also elsewhere on the board
/RAM/R_D0: U3.2 (A0), U5.13 (DQ7)
/RAM/R_D1: U3.3 (A1), U5.11 (DQ6)
/RAM/R_D2: U3.4 (A2), U5.10 (DQ5)
/RAM/R_D3: U3.5 (A3), U5.8 (DQ4)
/RAM/R_D4: U3.6 (A4), U5.7 (DQ3)
/RAM/R_D5: U3.7 (A5), U5.5 (DQ2)
/RAM/R_D6: U3.8 (A6), U5.4 (DQ1)
/RAM/R_D7: U3.9 (A7), U5.2 (DQ0)
/RAM/R_D8: U2.2 (A0), U5.53 (DQ15)
/RAM/R_D9: U2.3 (A1), U5.51 (DQ14)
/RAM/R_D10: U2.4 (A2), U5.50 (DQ13)
/RAM/R_D11: U2.5 (A3), U5.48 (DQ12)
/RAM/R_D12: U2.6 (A4), U5.47 (DQ11)
/RAM/R_D13: U2.7 (A5), U5.45 (DQ10)
/RAM/R_D14: U2.8 (A6), U5.44 (DQ9)
/RAM/R_D15: U2.9 (A7), U5.42 (DQ8)
GND: C2.2, C5.2, C6.2, C7.2, C8.2, C9.2, C10.2, C11.2, C12.2, C25.2, U2.10 (GND), U3.10 (GND), U5.6 (VSSQ), U5.12 (VSSQ), U5.28 (VSS), U5.36 (A12), U5.41 (VSS), U5.46 (VSSQ), U5.52 (VSSQ), U5.54 (VSS); also elsewhere on the board

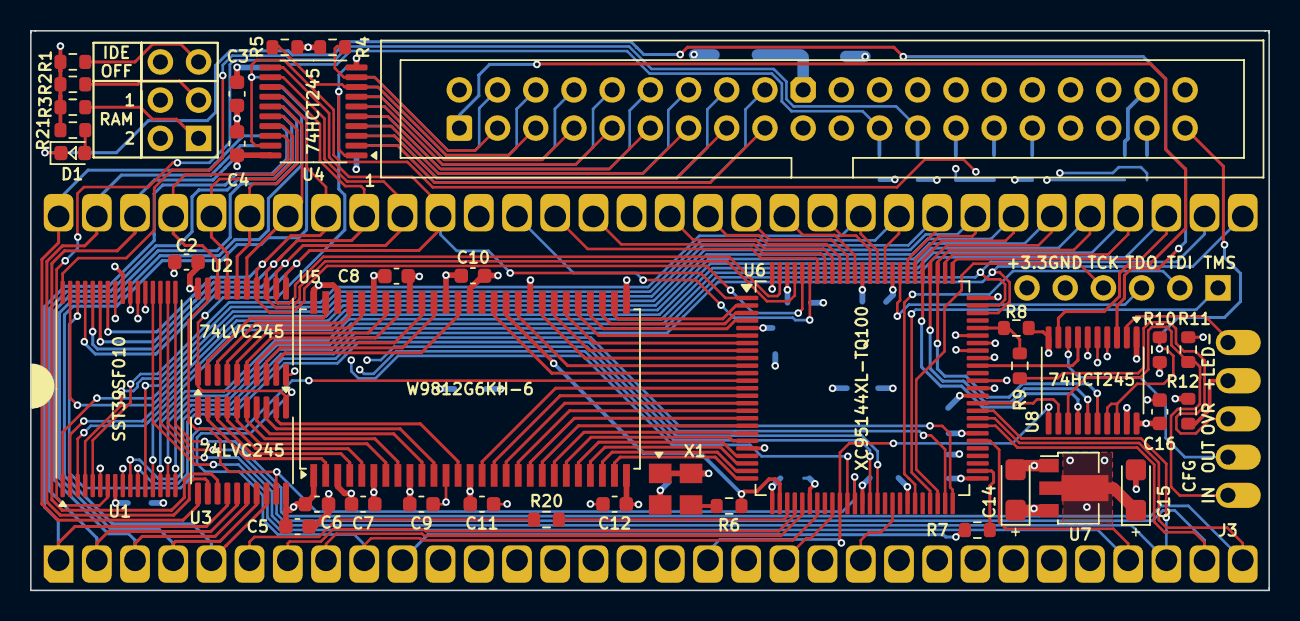
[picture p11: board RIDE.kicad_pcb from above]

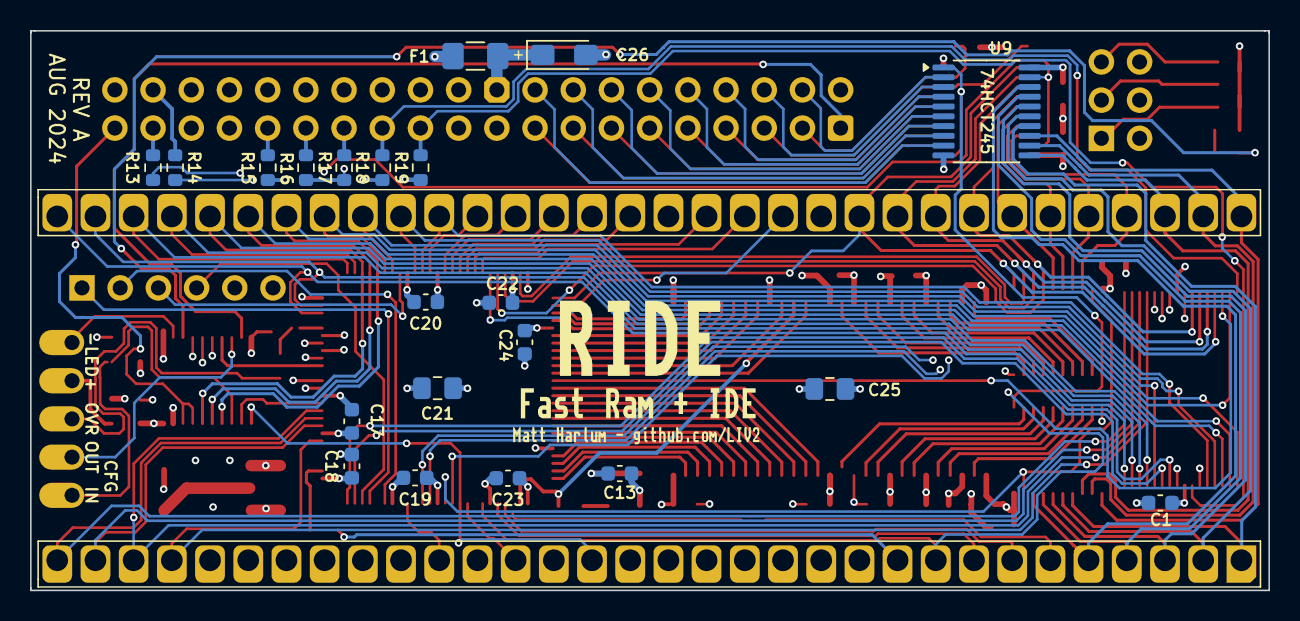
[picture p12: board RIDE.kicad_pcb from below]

Board: 4 copper layers, 82.3 x 37.2 mm, 67 parts (24 on the bottom side), 146 nets.

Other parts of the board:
kibuzzard-1: G***; kibuzzard-667ABBFF
kibuzzard-2: G***; kibuzzard-667CDE38
kibuzzard-3: G***; kibuzzard-667ABBF2

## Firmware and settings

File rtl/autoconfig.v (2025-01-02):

/*
 * Copyright (C) 2023 Matthew Harlum <matt@harlum.net>
 *
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
 * You should have received a copy of the GNU General Public License
 * along with this program; if not, write to the Free Software Foundation,
 * Inc., 51 Franklin Street, Fifth Floor, Boston, MA 02110-1301, USA.
 */
module Autoconfig (
    input [23:1] addr,
    input as_n,
    input clk,
    input rw,
    input [3:0] din,
    input reset_n,
    input ovr_detect,
    input bonus_en,
    input ide_enabled,
    input [1:0] ram_size,
    input [1:0] z2_state,
    input cfgin_n,
    input enable_maprom,
    output cfgout_n,
    output ram_access,
    output ide_access,
    output autoconfig_cycle,
    output reg [3:0] dout,
    output reg dtack,
    output reg ovl
);

`include "globalparams.vh"

// Autoconfig
localparam [15:0] mfg_id  = 16'd5194;
localparam [31:0] serial  = 32'd1;

reg ram_configured;
reg ide_configured;

reg [2:0] ide_base;
reg cdtv_configured;
reg cfgin;
reg cfgout;
reg maprom_enabled;

reg [2:0] zram_size;
reg [3:0] addr_match;
reg [1:0] ac_state;

localparam ac_ram  = 2'b00,
           ac_ide  = 2'b01,
           ac_done = 2'b10;

localparam SZ_0M = 2'b00,
           SZ_2M = 2'b01,
           SZ_4M = 2'b10,
           SZ_8M = 2'b11;

wire [7:0] prodid [0:1];

assign prodid[ac_ram] = 8'd8;
assign prodid[ac_ide] = 8'h9;

wire [3:0] boardSize [0:1];
assign boardSize[ac_ram] = {1'b1,zram_size};
assign boardSize[ac_ide] = 4'b0010; // 128K

assign autoconfig_cycle = (addr[23:16] == 8'hE8) && cfgin && !cfgout;

assign cfgout_n = ~cfgout;

// CDTV DMAC is first in chain.
// So we wait until it's configured before we talk
always @(posedge clk or negedge reset_n) begin
  if (!reset_n) begin
    cdtv_configured <= 0;
  end else begin
    if (addr[23:16] == 8'hE8 && addr[8:1] == 8'h24 && !as_n && !rw) begin
      cdtv_configured <= 1'b1;
    end
  end
end

// These need to be registered at the end of a bus cycle
always @(posedge as_n or negedge reset_n) begin
  if (!reset_n) begin
    cfgout <= 0;
    cfgin  <= 0;
  end else begin
`ifdef CDTV
    cfgin  <= ~cfgin_n && cdtv_configured;
`else
    cfgin  <= ~cfgin_n;
`endif
    cfgout <= (ac_state == ac_done);
  end
end

always @(posedge clk or negedge reset_n) begin
  if (!reset_n) begin
    zram_size <= 3'b000;
  end else begin
    case (ram_size)
      SZ_8M:   zram_size <= 3'b000;
      SZ_4M:   zram_size <= 3'b111;
      SZ_2M:   zram_size <= 3'b110;
      default: zram_size <= 3'b000;
    endcase
  end
end

always @(posedge clk or negedge reset_n)
begin
  if (!reset_n) begin
    dout           <= 'b0;
    ac_state       <= (ram_size == SZ_0M) ? (ac_ram + 1) : ac_ram;
    dtack          <= 0;
    ide_base       <= 3'b0;
    ide_configured <= 0;
    ram_configured <= 0;
    addr_match     <= 4'd0;
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

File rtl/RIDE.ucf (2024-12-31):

NET "DBUS<12>"    LOC = "P96";
NET "DBUS<13>"    LOC = "P97";
NET "DBUS<14>"    LOC = "P99";
NET "DBUS<15>"    LOC = "P1";
NET "ADDR<1>"     LOC = "P56";
NET "ADDR<2>"     LOC = "P60";
NET "ADDR<3>"     LOC = "P58";
NET "ADDR<4>"     LOC = "P59";
NET "ADDR<5>"     LOC = "P73";
NET "ADDR<6>"     LOC = "P74";
NET "ADDR<7>"     LOC = "P76";
NET "ADDR<8>"     LOC = "P77";
NET "ADDR<9>"     LOC = "P78";
NET "ADDR<10>"    LOC = "P79";
NET "ADDR<11>"    LOC = "P80";
NET "ADDR<12>"    LOC = "P81";
NET "ADDR<13>"    LOC = "P82";
NET "ADDR<14>"    LOC = "P85";
NET "ADDR<15>"    LOC = "P86";
NET "ADDR<16>"    LOC = "P87";
NET "ADDR<17>"    LOC = "P89";
NET "ADDR<18>"    LOC = "P90";
NET "ADDR<19>"    LOC = "P91";
NET "ADDR<20>"    LOC = "P92";
NET "ADDR<21>"    LOC = "P93";
NET "ADDR<22>"    LOC = "P94";
NET "ADDR<23>"    LOC = "P95";
NET "BERR_n"      LOC = "P42";
NET "UDS_n"       LOC = "P29";
NET "LDS_n"       LOC = "P30";
NET "RW"          LOC = "P32";
NET "AS_n"        LOC = "P28";
NET "RESET_n"     LOC = "P35";
NET "ECLK"        LOC = "P34";
NET "DTACK_n"     LOC = "P52";
NET "OVR_n"       LOC = "P71";
NET "CFGOUT_n"    LOC = "P61";
NET "CFGIN_n"     LOC = "P66";

NET "IDE_ENABLE"  LOC = "P40";
NET "IOR_n"       LOC = "P70";
NET "IOW_n"       LOC = "P68";
NET "IDECS1_n"    LOC = "P64";
NET "IDECS2_n"    LOC = "P63";
NET "IDEBUF_OE"   LOC = "P67";
NET "IDE_ROMEN"   LOC = "P12";
NET "ROM_BANK<0>" LOC = "P49";
NET "ROM_BANK<1>" LOC = "P50";
NET "MEMCLK"      LOC = "P27";

NET "RAM_SIZE<0>" LOC = "P36";
NET "RAM_SIZE<1>" LOC = "P39";

NET "MEMW_n"      LOC = "P14";
NET "RAS_n"       LOC = "P16";
NET "CAS_n"       LOC = "P15";
NET "CKE"         LOC = "P10";
NET "DQML"        LOC = "P13";
NET "DQMH"        LOC = "P11";
NET "RAMCS_n"     LOC = "P17";
NET "RAMOE_n"     LOC = "P37";
NET "BA<0>"       LOC = "P18";
NET "BA<1>"       LOC = "P19";
NET "MA<0>"       LOC = "P22";
NET "MA<1>"       LOC = "P23";
NET "MA<2>"       LOC = "P24";
NET "MA<3>"       LOC = "P25";
NET "MA<4>"       LOC = "P2";
NET "MA<5>"       LOC = "P3";
NET "MA<6>"       LOC = "P4";
NET "MA<7>"       LOC = "P6";
NET "MA<8>"       LOC = "P7";
NET "MA<9>"       LOC = "P8";
NET "MA<10>"      LOC = "P20";
NET "MA<11>"      LOC = "P9";

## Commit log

2024-12-31 Initial commit.
    [IDE.kicad_sch, RAM.kicad_sch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]
2025-01-21 Update JLC BOM & CPL * Include IDE Header and jumper block * Replace JLC part numbers with in-stock items (except flash)
    [IDE.kicad_sch, RAM.kicad_sch, RIDE.kicad_pcb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]
2025-12-04 Update BOM
    Add Digikey Part links (including new part number for Flash)
    Removed EOL flash part link from Mouser
    [IDE.kicad_sch, RAM.kicad_sch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]

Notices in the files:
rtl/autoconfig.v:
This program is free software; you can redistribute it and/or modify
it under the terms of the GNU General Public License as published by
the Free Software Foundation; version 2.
